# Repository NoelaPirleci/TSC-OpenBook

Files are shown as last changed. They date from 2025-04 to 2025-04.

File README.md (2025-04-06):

# TSC-OpenBook
# Descriere funcționalitate hardware

Proiectul se bazează pe microcontroller-ul **ESP32-C6**, care gestionează comunicarea cu toate componentele externe și senzorii conectați. Acest microcontroller oferă conectivitate **Wi-Fi** și **Bluetooth**, dar și suport pentru interfetele **SPI**, **I2C** și **UART**. Este conectat la 3V3 printr-un regulator de tensiune **LDO**, care primește energie de la o baterie **Li-Po** de 3.7V. 

Afisarea informațiilor se face utilizând un **display E-Paper** conectat prin **interfața SPI**, care are un consum redus de energie, fiind activ doar la actualizările ecranului. Informațiile afișate vor include data, ora, valorile senzorilor etc. 

Monitorizarea mediului se face cu ajutorul senzorului **BME688**, care măsoară temperatura, umiditatea și presiunea atmosferică, comunicând cu microcontroller-ul prin magistrala **I2C**. Modulul **RTC DS3231** este conectat și el la I2C și menține ora și data exactă, chiar și atunci când sistemul este oprit.

Prin **portul USB-C** se face alimentarea sistemului, care este conectat la circuitul de încărcare a bateriei utilizând **MCP73831**. Acesta controlează încărcarea bateriei Li-Po. Tensiunea va fi stabilită la **3.3V** pentru alimentarea senzorilor și a microcontroller-ului. Circuitul **MAX17048** este folosit pentru a monitoriza nivelul încărcării bateriei și furnizează informații despre tensiune și starea de încărcare prin I2C.

Consumul de energie este gestionat de ESP32-C6, care poate intra în **modul de consum redus**, permițând o durată lungă de viață a bateriei. Consumul în regim activ variază în funcție de sarcinile și componentele active în acel moment.

Pentru stocare, sistemul va folosi o **memorie externă NOR Flash**, conectată prin **SPI**, dar va exista și un slot pentru **card SD**, care va fi folosit pentru a loga local datele. Butoanele sunt conectate la **GPIO-uri** și vor fi folosite pentru resetare, bootare și alte acțiuni.

---

# Schema bloc

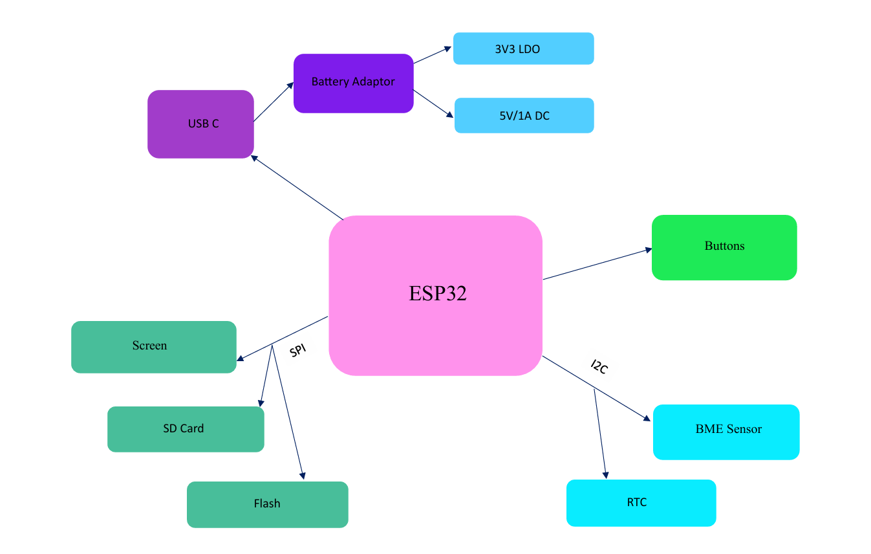
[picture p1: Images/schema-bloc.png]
scheme


# Descriere pini ESP32-C6

Pinii microcontroller-ului **ESP32-C6** sunt utilizați în cadrul a cinci categorii:

## 1. Interfața SPI
Este folosită pentru comunicarea componentelor care necesită viteze mari de transfer. Pinii utilizați sunt:
- **IO0**: linia **MOSI** unde microcontroller-ul va trimite date către perifericele SPI.
- **IO1**: linia **MISO** unde ESP32-C6 va primi date de la cardul SD.
- **IO2**: linia **SCK** care va genera semnalul de ceas pentru sincronizarea SPI.
- **IO3**: linia **CS** pentru memoria **Flash NOR**.
- **IO4**: linia **CS** pentru display-ul **E-paper**.
- **IO5**: linia **CS** pentru slotul de card **SD**.
- **IO6, IO7, IO8**: pentru semnalele de control ale **E-Paper**-ului: **reset**, **busy**, **data/command (DC)**. Acești pini sunt utilizați pentru a evita conflictele cu alte interfețe și permit o rutare eficientă a traseelor pe placă.

## 2. Interfața I2C
Este folosită pentru a conecta senzorii de mediu și circuitele de monitorizare a tensiunii sau a timpului. Această interfață va conecta componentele: **BME688**, **MAX17048**, **DS3231**. Pinii folosiți sunt:
- **IO15**: linia **SCL**, folosită pentru semnalul de ceas.
- **IO16**: linia **SDA**, care va transmite date bidirecțional între microcontroller și perifericele I2C. Acești pini sunt aleși pentru a nu se suprapune cu cei de la SPI sau UART și pentru a permite extinderea prin **Qwiic**.

## 3. Interfața UART
Este folosită pentru **debugging**, comunicare serială sau conectare la module externe. Pinii utilizați sunt:
- **IO17**: **TXD**, linia de ieșire a datelor de la ESP32 către PC sau consolă.
- **IO18**: **RXD**, linia de intrare a datelor către ESP32. Acești pini sunt utili în faza de dezvoltare pentru testare, dar pot fi folosiți și în aplicațiile finale, dacă UART nu este necesar.

## 4. Pini GPIO
Sunt folosiți pentru butoanele **boot**, **reset** sau **change**. Pinii utilizați sunt:
- **IO9**: este folosit pentru **BOOT** și permite intrarea în modul de programare.
- **EN**: este pinul hardware **RESET** al ESP32-C6.
- **IO10, IO11**: sunt utilizați pentru butoane suplimentare, care au diverse acțiuni în aplicație. Acești pini au fost aleși pentru că sunt disponibili în schema de referință ESP32-C6 și nu sunt partajați cu perifericele.

## 5. Alimentare
Pinii de alimentare sunt:
- **3V3**: este intrarea de alimentare stabilizată la 3.3V, provenind din regulatorul LDO alimentat de la bateria **Li-Po**.
- **GND**: conexiunea de masă.

# Bill of Materials

| CNT | VAL | Device | Package | Parts | PURCHASE | DATASHEET |
| --- | ----- | --- | --- | ----- | --- | --- |
| 1 |  | ADAFRUIT_LEDCHIP-LED0603 | 0603 | CHG_LED | https://www.digikey.com/en/products/detail/w%C3%BCrth-elektronik/150060RS75000/4489901 | https://www.we-online.com/components/products/datasheet/150060RS75000.pdf |
| 1 | 0.1uF/50V | ESP32_WROVER_EAGLE-LTSPICE_C0402 | 0402 | EPD_C3 | https://www.digikey.com/en/products/detail/samsung-electro-mechanics/CL05B104KB5NNNC/11696318 | https://weblib.samsungsem.com/mlcc/mlcc-ec-data-sheet.do?partNumber=CL05B104KB5NNN |
| 1 | 0.47 | ESP32_WROVER_EAGLE-LTSPICE_RR0402 | 0402 | R3 | https://www.digikey.com/en/products/detail/panasonic-electronic-components/ERJ-2BQJR47X/5647384 | https://industrial.panasonic.com/cdbs/www-data/pdf/RDN0000/AOA0000C313.pdf |
| 1 | 100K | ESP32_WROVER_EAGLE-LTSPICE_RR0402 | 0402 | R_PWRUSB | https://www.digikey.com/en/products/detail/panasonic-electronic-components/ERJ-2RKF1003X/192081 | https://industrial.panasonic.com/cdbs/www-data/pdf/RDA0000/AOA0000C304.pdf |
| 8 | 100nF | ESP32_WROVER_EAGLE-LTSPICE_C0402 | 0402 | C1, C2, C3_USB, C5, C7, C8, C9, C_DELAY | https://www.digikey.com/en/products/detail/samsung-electro-mechanics/CL05B104KP5NNNC/3886660 | https://mm.digikey.com/Volume0/opasdata/d220001/medias/docus/609/CL05B104KP5NNNC_Spec.pdf |
| 1 | 100uF | RCL_CPOL-EUCT3528 | 3528 | C_TANT | https://ro.mouser.com/ProductDetail/KEMET/T491B107M006AT?qs=U312oeP%2FpiHOgyk6KO2m0g%3D%3D | https://ro.mouser.com/datasheet/2/447/KEM_T2005_T491-3316937.pdf
| 16 | 10K | ESP32_WROVER_EAGLE-LTSPICE_RR0402 | 0402 | R1, R1_PINH1, R1_PINH2, R2-PINH1, R2_PINH2, R4, R5, R6, R7, R8, R9, R10, R_BOOT, R_CHANGE, R_CL1, R_RESET | https://www.digikey.com/en/products/detail/panasonic-electronic-components/ERJ-2RKF1002X/192073 | https://industrial.panasonic.com/cdbs/www-data/pdf/RDA0000/AOA0000C304.pdf |
| 1 | 10uF | ESP32_WROVER_EAGLE-LTSPICE_C0402 | 0402 | C6 | https://www.digikey.com/en/products/detail/samsung-electro-mechanics/CL05A106MP5NUNC/3887108 | https://mm.digikey.com/Volume0/opasdata/d220001/medias/docus/2614/CL05A106MP5NUNC_Spec.pdf |
| 1 | 112A-TAAR-R03_ATTEND | 112A-TAAR-R03_ATTEND |  | J4 | https://www.digikey.ro/en/products/detail/attend-technology/112A-TAAR-R03/17633923 | https://www.attend.com.tw/data/download/file/112A-TAAR-R03_Spec.pdf |
| 1 | 15 | ESP32_WROVER_EAGLE-LTSPICE_RR0402 | 0402 | R_CAPACITOR | https://www.digikey.com/en/products/detail/panasonic-electronic-components/ERJ-2RKF15R0X/192142 | https://industrial.panasonic.com/cdbs/www-data/pdf/RDA0000/AOA0000C304.pdf |
| 1 | 1uF | ESP32_WROVER_EAGLE-LTSPICE_C0402 | 0402 | C4 | https://www.digikey.com/en/products/detail/samsung-electro-mechanics/CL05A105KO5NNNC/3886725 | https://mm.digikey.com/Volume0/opasdata/d220001/medias/docus/609/CL05A105KO5NNNC_Spec_5-2-19.pdf |
| 9 | 1uF/50V | ESP32_WROVER_EAGLE-LTSPICE_C0402 | 0402 | EPD_C1, EPD_C2, EPD_C4, EPD_C5, EPD_C6, EPD_C7, EPD_C8, EPD_C9, EPD_C10 | https://www.digikey.com/en/products/detail/murata-electronics/GRM155R61H105KE05D/13531808 | https://search.murata.co.jp/Ceramy/image/img/A01X/G101/ENG/GRM155R61H105KE05-01A.pdf |
| 1 | 2.2 | ESP32_WROVER_EAGLE-LTSPICE_RR0402 | 0402 | R2 | https://www.digikey.com/en/products/detail/panasonic-electronic-components/ERJ-2GEJ2R2X/282078 | https://api.pim.na.industrial.panasonic.com/file_stream/main/fileversion/1242 |
| 1 | 200 | ESP32_WROVER_EAGLE-LTSPICE_RR0402 | 0402 | R1_BAT | https://www.digikey.com/en/products/detail/panasonic-electronic-components/ERJ-2RKF2000X/192215 | https://industrial.panasonic.com/cdbs/www-data/pdf/RDA0000/AOA0000C304.pdf |
| 2 | 20V/4.2A/52mO/1.4W | ESP32_WROVER_SPARKFUN-DISCRETESEMI_MOSFET_PCH-DMG2305UX-7 |  | Q1, Q2 | https://www.digikey.ro/en/products/detail/diodes-incorporated/DMG2305UX-7/4340667 | https://www.diodes.com/assets/Datasheets/DMG2305UX.pdf |
| 1 | 2K | ESP32_WROVER_EAGLE-LTSPICE_RR0402 | 0402 | R2_BAT | https://www.digikey.com/en/products/detail/panasonic-electronic-components/ERJ-2RKF2001X/192194 | https://industrial.panasonic.com/cdbs/www-data/pdf/RDA0000/AOA0000C304.pdf |
| 5 | 4.7uF | ESP32_WROVER_EAGLE-LTSPICE_C0402 | 0402 | C1_BAT, C1_BAT1, C2_BAT, C2_BAT1, C4_USB | https://www.digikey.com/en/products/detail/samsung-electro-mechanics/CL05A475KQ5NRNC/3887139 | https://mm.digikey.com/Volume0/opasdata/d220001/medias/docus/41/CL05A475KQ5NRNC_Spec.pdf |
| 1 | 4.7uF/25V | ESP32_WROVER_EAGLE-LTSPICE_C0402 | 0402 | C3 | https://www.digikey.com/en/products/detail/murata-electronics/GRM155C61E475ME15D/16821133 | https://search.murata.co.jp/Ceramy/image/img/A01X/G101/ENG/GRM155C61E475ME15-01A.pdf |
| 2 | 5k1 | ESP32_WROVER_EAGLE-LTSPICE_RR0402 | 0402 | R1_USB, R2_USB | https://www.digikey.com/en/products/detail/panasonic-electronic-components/ERJ-2GEJ512X/147044 | https://api.pim.na.industrial.panasonic.com/file_stream/main/fileversion/1242 |
| 1 | 68uH | 744043680IND_4828-WE-TPC_WRE |  | L1 | https://www.digikey.de/en/products/detail/w%C3%BCrth-elektronik/744043680/1638515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 | https://www.we-online.com/components/products/datasheet/744043680.pdf |
| 1 | BD5229G-TR | BD5229G-TR |  | U6 | https://www.digikey.com/en/products/detail/rohm-semiconductor/BD5229G-TR/658502 | https://www.rohm.com/datasheet?p=BD5229G&dist=Digi-key&media=referral&source=digi-key.com&campaign=Digi-key |
| 1 | BME688 | ESP32_WROVER_BME680_BME680 |  | U8 | https://www.digikey.ro/en/products/detail/bosch-sensortec/BME688/13681261 | https://www.bosch-sensortec.com/media/boschsensortec/downloads/datasheets/bst-bme688-ds000.pdf |
| 3 | BUTTON_CUSYOMV1 | BUTTON_CUSYOMV1 |  | BOOT_BUTTON, CHANGE_BUTTON, RESET_BUTTON |  |  |
| 1 | CPH3225A | CPH3225A |  | C_SUPERCAP | https://www.digikey.com/en/products/detail/seiko-instruments/CPH3225A/8692444 | https://mm.digikey.com/Volume0/opasdata/d220001/medias/docus/6537/rev05-CPHCPM.pdf |
| 1 | DS3231SN# | DS3231SN# |  | U3 | https://www.digikey.com/en/products/detail/analog-devices-inc-maxim-integrated/DS3231SN/1197576 | https://www.analog.com/media/en/technical-documentation/data-sheets/DS3231.pdf |
| 1 | ESP32-C6-WROOM-1-N8 | ESP32-C6-WROOM-1-N8 |  | U1 | https://www.digikey.com/en/products/detail/espressif-systems/ESP32-C6-WROOM-1-N8/17728866 | https://www.espressif.com/sites/default/files/documentation/esp32-c6-wroom-1_wroom-1u_datasheet_en.pdf |
| 1 | ESP32C6_VARISTORCN1812 | ESP32C6_VARISTORCN1812 |  | PFMF.050.1 | https://www.digikey.com/en/products/detail/schurter-inc/PFMF-050-2/1731348 | https://us.schurter.com/en/datasheet/typ_PFMF.pdf |
| 2 | ESP32_WROVER_AVX---SD0805S020S1R0 | ESP32_WROVER_AVX---SD0805S020S1R0 |  | D2, D7 | https://www.digikey.gr/en/products/detail/kyocera-avx/SD0805S020S1R0/3749517 | https://datasheets.kyocera-avx.com/schottky.pdf |
| 1 | FH34SRJ-24S-0.5SH_99_ | FH34SRJ-24S-0.5SH_99_ |  | J1 | https://www.digikey.com/en/products/detail/hirose-electric-co-ltd/FH34SRJ-24S-0-5SH-99/5132529 | https://www.hirose.com/en/product/document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 |
| 1 | MAX17048G+T10 | MAX17048G+T10 |  | U2 | https://www.digikey.com/en/products/detail/analog-devices-inc-maxim-integrated/MAX17048G-T10/3758921 | https://datasheets.maximintegrated.com/en/ds/MAX17048-MAX17049.pdf |
| 3 | MBR0530 | MBR0530 |  | D3, D4, D5 | https://eu.mouser.com/ProductDetail/Micro-Commercial-Components-MCC/MBR0530-TP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 | https://eu.mouser.com/datasheet/2/258/MBR0520_MBR0580_SOD123_-2492194.pdf |
| 1 | MCP73831 | ESP32_WROVER_SPARKFUN-IC-POWER_MCP73831 |  | U7 | https://www.digikey.com/en/products/detail/microchip-technology/MCP73831T-2ACI-OT/964301 | https://ww1.microchip.com/downloads/en/DeviceDoc/MCP73831-Family-Data-Sheet-DS20001984H.pdf |
| 6 | PGB1010603MR | PGB1010603MR |  | D6, D8, D9, D10, D11, D12 | https://www.digikey.com/en/products/detail/littelfuse-inc/PGB1010603MR/715755 | https://www.littelfuse.com/assetdocs/pulseguard-esd-suppressors-pgb1-datasheet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 |
| 1 | QWIIC_RIGHT_ANGLE | QWIIC_CONNECTORJS-1MM |  | J3 | https://www.sparkfun.com/qwiic-jst-connector-smd-4-pin-horizontal.html | https://cdn.sparkfun.com/assets/parts/1/2/2/8/9/Qwiic_Connector_Datasheet.pdf |
| 1 | SAMACSYS_PARTS_USB4110-GF-A | SAMACSYS_PARTS_USB4110-GF-A |  | J2 | https://www.digikey.ro/en/products/detail/gct/USB4110-GF-A/10384547 | https://gct.co/files/specs/usb4110-spec.pdf?v=6b2a6292-70a5-4bd5-a7e5-0f3fe03e015f |
| 1 | SI1308EDL-T1-GE3 | SI1308EDL-T1-GE3 |  | Q3 | https://www.digikey.com/en/products/detail/vishay-siliconix/SI1308EDL-T1-GE3/4876435 | https://www.vishay.com/docs/63399/si1308edl.pdf |
| 1 | USBLC6-2SC6Y | USBLC6-2SC6Y |  | D1 | https://www.digikey.com/en/products/detail/stmicroelectronics/USBLC6-2SC6Y/2819177 | https://www.st.com/content/ccc/resource/technical/document/datasheet/group0/94/15/6c/58/ba/91/46/42/DM00055262/files/DM00055262.pdf/jcr:content/translations/en.DM000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 |
| 1 | W25Q512JVEIQ | W25Q512JVEIQ |  | U4 | https://www.digikey.com/en/products/detail/winbond-electronics/W25Q512JVEIQ/10244706 | https://www.winbond.com/resource-files/W25Q512JV%20SPI%20RevB%2006252019%20KMS.pdf |
| 1 | XC6220A331MR-G | XC6220A331MR-G |  | U5 | https://www.digikey.in/en/products/detail/torex-semiconductor-ltd/XC6220A331MR-G/10165775 | https://product.torexsemi.com/system/files/series/xc6220.pdf |

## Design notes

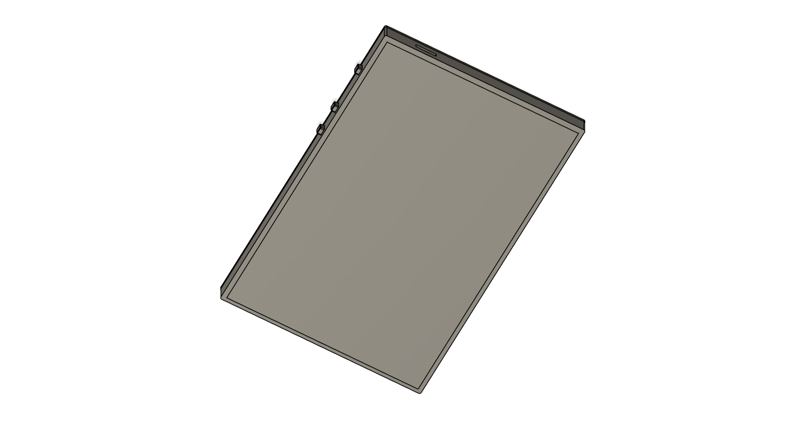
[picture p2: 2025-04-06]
Images/front_image.png

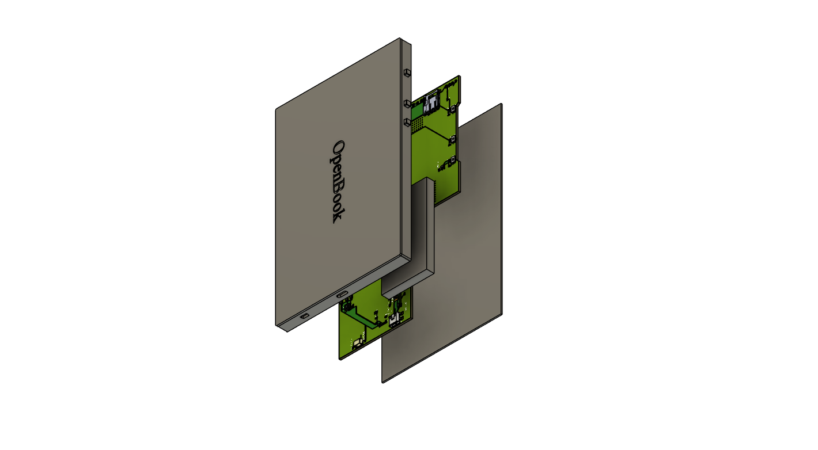
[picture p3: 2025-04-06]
Images/exploded_view.png

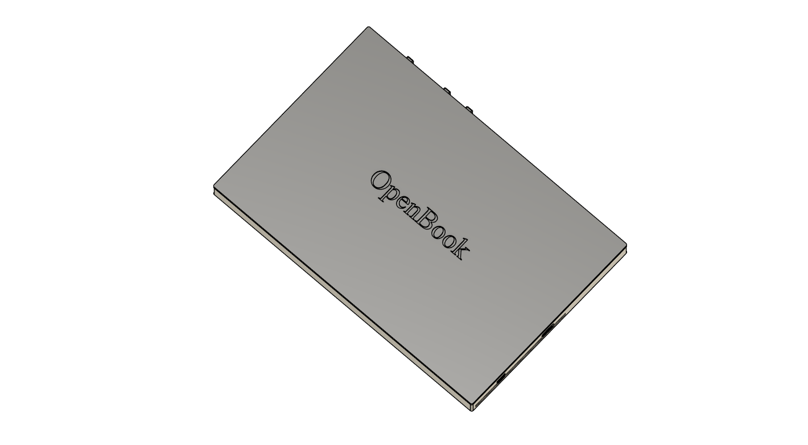
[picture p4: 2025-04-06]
Images/back_image.png

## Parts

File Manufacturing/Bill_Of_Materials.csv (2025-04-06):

Qty | Value | Device | Package | Parts | Description | ARROW_PART_NUMBER | ARROW_PRICE-STOCK | DESCRIPTION | HEIGHT | MANUFACTURER_NAME | MANUFACTURER_PART_NUMBER | MOUSER_PART_NUMBER | MOUSER_PRICE-STOCK | POPULARITY
1 |  | ADAFRUIT_LED | ADAFRUIT_CHIP-LED0603 | CHG_LED | LED
1 |  | SJ | SJ | SJ1 | SMD solder JUMPER |  |  |  |  |  |  |  |  | 3
1 | 0.47 | ESP32_WROVER_EAGLE-LTSPICE_R | ESP32_WROVER_EAGLE-LTSPICE_R0402 | R3 | RESISTOR, European symbol
1 | 100K | ESP32_WROVER_EAGLE-LTSPICE_R | ESP32_WROVER_EAGLE-LTSPICE_R0402 | R1_PWRUSB | RESISTOR, European symbol
4 | 100nF | EAGLE-LTSPICE_C | ESP32_WROVER_EAGLE-LTSPICE_C0402 | C1, C4_USB, C9, C_DELAY | CAPACITOR, European symbol
4 | 100nF | ESP32_WROVER_EAGLE-LTSPICE_C | ESP32_WROVER_EAGLE-LTSPICE_C0402 | C2, C6, C8, C10 | CAPACITOR, European symbol
1 | 100uF TANT | RCL_CPOL-EU | RCL_CT3528 | C3 | POLARIZED CAPACITOR, European symbol
16 | 10K | ESP32_WROVER_EAGLE-LTSPICE_R | ESP32_WROVER_EAGLE-LTSPICE_R0402 | R1, R1-PINH, R1_PINH1, R2-PINH, R2_PINH1, R4, R5, R6, R7, R8, R9, R10, R_BOOT, R_CHANGE, R_CL1, R_RESET | RESISTOR, European symbol
1 | 10uF | ESP32_WROVER_EAGLE-LTSPICE_C | ESP32_WROVER_EAGLE-LTSPICE_C0402 | C7 | CAPACITOR, European symbol
1 | 112A-TAAR-R03_ATTENDSDCARD | 112A-TAAR-R03_ATTENDSDCARD | 112ATAARR03ATTEND | J4 | Micro SD Card Socket, Push-Push Type, Top Mount, SMT, H=1.83mm, 10u
1 | 15 | ESP32_WROVER_EAGLE-LTSPICE_R | ESP32_WROVER_EAGLE-LTSPICE_R0402 | R_CAPACITOR | RESISTOR, European symbol
1 | 1uF | ESP32_WROVER_EAGLE-LTSPICE_C | ESP32_WROVER_EAGLE-LTSPICE_C0402 | C5 | CAPACITOR, European symbol
10 | 1uF/50V | ESP32_WROVER_EAGLE-LTSPICE_C | ESP32_WROVER_EAGLE-LTSPICE_C0402 | EPD_C1, EPD_C2, EPD_C5, EPD_C6, EPD_C7, EPD_C8, EPD_C9, EPD_C10, EPD_C11, EPD_C12 | CAPACITOR, European symbol
1 | 2.2 | ESP32_WROVER_EAGLE-LTSPICE_R | ESP32_WROVER_EAGLE-LTSPICE_R0402 | R2 | RESISTOR, European symbol
1 | 200 | ESP32_WROVER_EAGLE-LTSPICE_R | ESP32_WROVER_EAGLE-LTSPICE_R0402 | R1_BAT | RESISTOR, European symbol
2 | 20V/4.2A/52m?/1.4W | ESP32_WROVER_SPARKFUN-DISCRETESEMI_MOSFET_PCH | ESP32_WROVER_SPARKFUN-DISCRETESEMI_SOT23-3 | Q1, Q2 | P-channel MOSFETs
1 | 2K | ESP32_WROVER_EAGLE-LTSPICE_R | ESP32_WROVER_EAGLE-LTSPICE_R0402 | R2_BAT | RESISTOR, European symbol
1 | 4.7uF | EAGLE-LTSPICE_C | ESP32_WROVER_EAGLE-LTSPICE_C0402 | C5_USB | CAPACITOR, European symbol
4 | 4.7uF | ESP32_WROVER_EAGLE-LTSPICE_C | ESP32_WROVER_EAGLE-LTSPICE_C0402 | C1_BAT, C1_BAT1, C1_BAT2, C2_BAT | CAPACITOR, European symbol
1 | 4.7uF/25V | EAGLE-LTSPICE_C | ESP32_WROVER_EAGLE-LTSPICE_C0402 | C4 | CAPACITOR, European symbol
2 | 5k1 | ESP32_WROVER_EAGLE-LTSPICE_R | ESP32_WROVER_EAGLE-LTSPICE_R0402 | R2-USB, R2-USB1 | RESISTOR, European symbol
1 | 68uH | 744043680 | IND_4828-WE-TPC_WRE | L1
1 | BD5229G-TRBD5229 | BD5229G-TRBD5229 | SOT95P280X125-5N | IC1 | Voltage Detector with Adjustable Delay Time: CMOS processes are utilized to develop high precision, low current consumption CMOS reset ICs that allow arbitrary setting of the delay time. The extensive lineup includes both Nch Open Drain and CMOS output types in a wide range of detection voltages (from 2.3V to 6.0V, in 0.1V steps), enabling selection of the ideal solution based on customer requirements. In addition, the entire series is of course both lead-free and RoHS-compliant.
3 | BUTTON_CUSYOMV1BUTON | BUTTON_CUSYOMV1BUTON | MYBUTTON | BOOT_BUTTON, CHANGE_BUTTON, RESET_BUTTON
1 | CPH3225ASUPERCAP | CPH3225ASUPERCAP | CAPCP3225X100N | C10_SUPERCAP | Cap 0.011F 3.3V 1210 Flat Check availability
1 | DS3231SN#DS3231 | DS3231SN#DS3231 | SOIC127P1032X265-16N | U3 | Real Time Clock Serial 16-Pin SOIC W T/R Check availability
1 | ESP32-C6-WROOM-1-N8 | ESP32-C6-WROOM-1-N8ESP32 | XCVR_ESP32-C6-WROOM-1-N8 | U2 | Check availability
1 | ESP32C6_VARISTOR | ESP32C6_VARISTOR | ESP32C6_VARISTOR_CT/CN1812 | PFMF.050.1 | VARISTOR
2 | ESP32_WROVER_AVX---SD0805S020S1R0_AVX_SD0805S020S1R0_0_0 | ESP32_WROVER_AVX---SD0805S020S1R0_AVX_SD0805S020S1R0_0_0 | ESP32_WROVER_AVX---SD0805S020S1R0_AVX_SD0805S020S1R0_0 | D2, D7 | Schottky Barrier Rectifier Diode
1 | ESP32_WROVER_BME680_BME680BME | ESP32_WROVER_BME680_BME680BME | ESP32_WROVER_BME680_PSON80P300X300X100-8N | SENSOR2 | Integrated Environmental Unit
1 | ESP32_WROVER_SPARKFUN-IC-POWER_MCP73831ICPOWER | ESP32_WROVER_SPARKFUN-IC-POWER_MCP73831ICPOWER | ESP32_WROVER_SPARKFUN-IC-POWER_SOT23-5 | MCP73831 | MCP73831T Li-Ion, Li-Pol Controller
1 | FH34SRJ-24S-0.5SH_99_FH34 | FH34SRJ-24S-0.5SH_99_FH34 | FH34SRJ24S05SH99 | J1 | (0.50mm) Surface Mount, Right Angle
1 | MAX17048G+T10MAX170 | MAX17048G+T10MAX170 | SON50P200X200X80-9N | U4 | Check availability
3 | MBR0530MBR | MBR0530MBR | SOD3716X135N | D3, D4, D5 | ON SEMICONDUCTOR - MBR0530 - DIODE, SCHOTTKY, 0.5A, 30V, SOD-123
6 | PGB1010603MRDIOC | PGB1010603MRDIOC | DIOC1608X36N | D6, D8, D9, D10, D11, D12 | Check availability
1 | QWIIC_RIGHT_ANGLE | QWIIC_CONNECTOR | JST04_1MM_RA | J3 | SparkFun I2C Standard Qwiic Connector
1 | SAMACSYS_PARTS_USB4110-GF-AUSB | SAMACSYS_PARTS_USB4110-GF-AUSB | SAMACSYS_PARTS_USB4110GFA | J2 | CONN USB 2.0 TYPE-C R/A SMT
1 | SI1308EDL-T1-GE3SI13 | SI1308EDL-T1-GE3SI13 | SOT65P210X110-3N | Q3 | MOSFET N-Ch 30V 1.5A TrenchFET SC70 Vishay Si1308EDL-T1-GE3 N-channel MOSFET Transistor, 1.5 A, 30 V, 3-Pin SC-70
12 | TPMODEL | TPMODEL | TP20R | TP1, TP2, TP3, TP7, TP8, TP9, TP10, TP12, TP13, TP15, TP16, TP17 | Test pad
5 | TPTP20R | TPMODEL | TP20R | TP4, TP5, TP6, TP11, TP14 | Test pad
1 | USBLC6-2SC6YUSBL | USBLC6-2SC6YUSBL | SOT95P280X145-6N | D1 | Low Cap. ESD Protection Auto SOT-23-6 STMicroelectronics USBLC6-2SC6Y, Dual Uni-Directional TVS Diode Array, 6-Pin SOT-23
1 |  |  | SON127P600X800X80-9N | U1 | Check availability
1 | XC6220A331MR-G | XC6220A331MR-G | SOT95P280X120-5N | IC4 | LDO Voltage Regulators |  |  | LDO Voltage Regulators | 1.2mm | Torex | XC6220A331MR-G | 865-XC6220A331MR-G | https://www.mouser.co.uk/ProductDetail/Torex-Semiconductor/XC6220A331MR-G?qs=AsjdqWjXhJ8ZSWznL1J0gg%3D%3D

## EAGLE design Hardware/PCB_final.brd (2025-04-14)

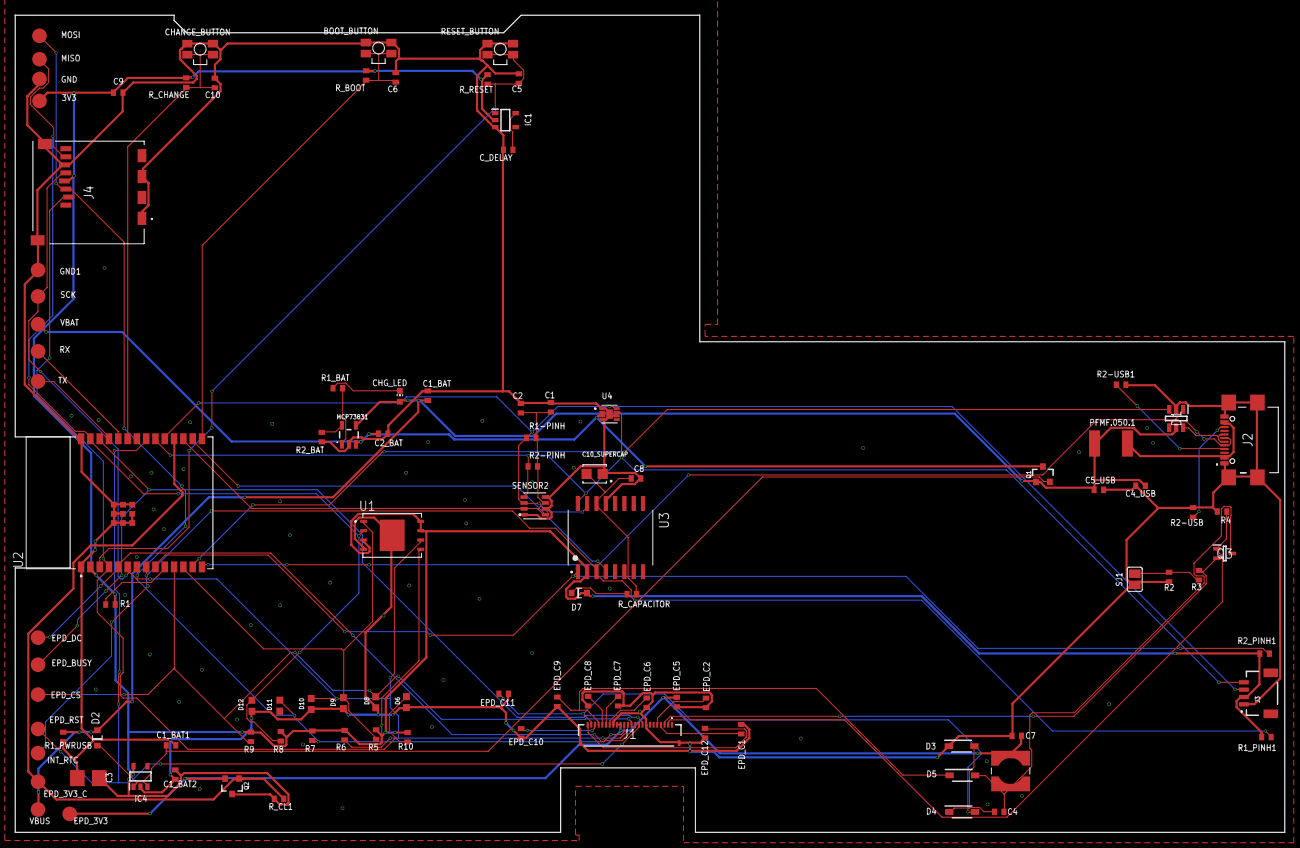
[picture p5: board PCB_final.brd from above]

Board: 2 copper layers, 173.4 x 111.6 mm, 103 parts (0 on the bottom side), 55 nets.

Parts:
3V3: TPMODEL; TP20R
BOOT_BUTTON: BUTTON_CUSYOMV1BUTON; MYBUTTON
C1, C2, C4_USB, C6, C8, C9, C10: 100nF; ESP32_WROVER_EAGLE-LTSPICE_C0402
C1_BAT, C1_BAT1, C1_BAT2, C2_BAT, C5_USB: 4.7uF; ESP32_WROVER_EAGLE-LTSPICE_C0402
C3: 100uF TANT; RCL_CT3528
C4: 4.7uF/25V; ESP32_WROVER_EAGLE-LTSPICE_C0402
C5: 1uF; ESP32_WROVER_EAGLE-LTSPICE_C0402
C7: 10uF; ESP32_WROVER_EAGLE-LTSPICE_C0402
C10_SUPERCAP: CPH3225ASUPERCAP; CAPCP3225X100N
CHANGE_BUTTON: BUTTON_CUSYOMV1BUTON; MYBUTTON
CHG_LED: ADAFRUIT_CHIP-LED0603
C_DELAY: 100nF; ESP32_WROVER_EAGLE-LTSPICE_C0402
D1: USBLC6-2SC6YUSBL; SOT95P280X145-6N
D2, D7: ESP32_WROVER_AVX---SD0805S020S1R0_AVX_SD0805S020S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; ESP32_WROVER_AVX---SD0805S020S1R0_AVX_SD0805S020S1R0_0
D3, D4, D5: MBR0530MBR; SOD3716X135N
D6, D8, D9, D10, D11, D12: PGB1010603MRDIOC; DIOC1608X36N
EPD_3V3, EPD_3V3_C: TPMODEL; TP20R
EPD_BUSY: TPMODEL; TP20R
EPD_C1, EPD_C2, EPD_C5, EPD_C6, EPD_C7, EPD_C8, EPD_C9, EPD_C10, EPD_C11, EPD_C12: 1uF/50V; ESP32_WROVER_EAGLE-LTSPICE_C0402
EPD_CS: TPMODEL; TP20R
EPD_DC: TPTP20R; TP20R
EPD_RST: TPMODEL; TP20R
GND, GND1: TPTP20R; TP20R
IC1: BD5229G-TRBD5229; SOT95P280X125-5N
IC4: XC6220A331MR-G; SOT95P280X120-5N
INT_RTC: TPMODEL; TP20R
J1: FH34SRJ-24S-0.5SH_99_FH34; FH34SRJ24S05SH99
J2: SAMACSYS_PARTS_USB4110-GF-AUSB; SAMACSYS_PARTS_USB4110GFA
J3: QWIIC_RIGHT_ANGLE; JST04_1MM_RA
J4: 112A-TAAR-R03_ATTENDSDCARD; 112ATAARR03ATTEND
L1: 68uH; IND_4828-WE-TPC_WRE
MCP73831: ESP32_WROVER_SPARKFUN-IC-POWER_MCP73831ICPOWER; ESP32_WROVER_SPARKFUN-IC-POWER_SOT23-5
MISO: TPTP20R; TP20R
MOSI: TPMODEL; TP20R
PFMF.050.1: ESP32C6_VARISTOR; ESP32C6_VARISTOR_CT/CN1812
Q1, Q2: 20V/4.2A/52mΩ/1.4W; ESP32_WROVER_SPARKFUN-DISCRETESEMI_SOT23-3
Q3: SI1308EDL-T1-GE3SI13; SOT65P210X110-3N
R1, R1-PINH, R1_PINH1, R2-PINH, R2_PINH1, R4, R5, R6, R7, R8, R9, R10: 10K; ESP32_WROVER_EAGLE-LTSPICE_R0402
R1_BAT: 200; ESP32_WROVER_EAGLE-LTSPICE_R0402
R1_PWRUSB: 100K; ESP32_WROVER_EAGLE-LTSPICE_R0402
R2: 2.2; ESP32_WROVER_EAGLE-LTSPICE_R0402
R2-USB, R2-USB1: 5k1; ESP32_WROVER_EAGLE-LTSPICE_R0402
R2_BAT: 2K; ESP32_WROVER_EAGLE-LTSPICE_R0402
R3: 0.47; ESP32_WROVER_EAGLE-LTSPICE_R0402
RESET_BUTTON: BUTTON_CUSYOMV1BUTON; MYBUTTON
RX: TPMODEL; TP20R
R_BOOT: 10K; ESP32_WROVER_EAGLE-LTSPICE_R0402
R_CAPACITOR: 15; ESP32_WROVER_EAGLE-LTSPICE_R0402
R_CHANGE: 10K; ESP32_WROVER_EAGLE-LTSPICE_R0402
R_CL1: 10K; ESP32_WROVER_EAGLE-LTSPICE_R0402
R_RESET: 10K; ESP32_WROVER_EAGLE-LTSPICE_R0402
SCK: TPMODEL; TP20R
SENSOR2: ESP32_WROVER_BME680_BME680BME; ESP32_WROVER_BME680_PSON80P300X300X100-8N
SJ1: SJ
TX: TPMODEL; TP20R
U1: W25Q512JVEIQ"; SON127P600X800X80-9N
U2: ESP32-C6-WROOM-1-N8; XCVR_ESP32-C6-WROOM-1-N8
U3: DS3231SN#DS3231; SOIC127P1032X265-16N
U4: MAX17048G+T10MAX170; SON50P200X200X80-9N
VBAT: TPMODEL; TP20R
VBUS: TPTP20R; TP20R

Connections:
3V3: 3V3.TP, C1_BAT2.1, C3.+, C9.1, D7.2, IC1.2, IC4.5, J3.2, J4.P4, Q2.3, R1.2, R1_PINH1.2, R2_PINH1.2, R5.2, R6.2, R7.2, R8.2, R9.2, R10.2, R_BOOT.2, R_CHANGE.2, R_CL1.2, R_RESET.2, U1.3, U1.7, U1.8, U2.2, U3.2
32KHZ: R2_PINH1.1, U2.9, U3.1
DN: D1.4, J2.A7, J2.B7
DP: D1.6, J2.A6, J2.B6
EPD_3V3: C7.1, EPD_3V3.TP, EPD_C5.2, J1.15, J1.16, L1.2, Q2.2
EPD_3V3_C: EPD_3V3_C.TP, Q2.1, R_CL1.1, U2.18
EPD_BUSY: EPD_BUSY.TP, J1.9, U2.26
EPD_CS: D8.2, EPD_CS.TP, J1.12, R9.1, U2.11
EPD_DC: EPD_DC.TP, J1.11, U2.5
EPD_RST: EPD_RST.TP, J1.10, U2.21
FLASH_CS: D9.2, R5.1, U1.1, U2.12
GDR: J1.2, Q3.1, R4.2
GND: BOOT_BUTTON.1, BOOT_BUTTON.2, C1.2, C1_BAT.2, C1_BAT1.2, C1_BAT2.2, C2.2, C2_BAT.2, C3.-, C4_USB.2, C5.2, C5_USB.2, C6.2, C7.2, C8.2, C9.2, C10.2, C10_SUPERCAP.1, CHANGE_BUTTON.1, CHANGE_BUTTON.2, C_DELAY.2, D1.2, D3.1, D6.1, D8.1, D9.1, D10.1, D12.1, EPD_C1.1, EPD_C2.1, EPD_C5.1, EPD_C6.1, EPD_C7.1, EPD_C8.1, EPD_C9.1, EPD_C10.1, EPD_C11.1, EPD_C12.1, GND.TP, GND1.TP, IC1.3, IC4.2, J1.8, J1.17, J1.MP1, J1.MP2, J2.A1, J2.A12, J2.B1, J2.B12, J2.MP1, J2.MP2, J2.MP3, J2.MP4, J3.1, J4.G1, J4.G2, J4.G3, J4.G4, J4.P6, MCP73831.2, R1_PWRUSB.1, R2.1, R2-USB.2, R2-USB1.1, R2_BAT.1, R4.1, RESET_BUTTON.1, RESET_BUTTON.2, SENSOR2.1, SENSOR2.5, SENSOR2.7, SJ1.1, U1.4, U1.9, U2.1, U2.28, U2.29_1, U2.29_2, U2.29_3, U2.29_4, U2.29_5, U2.29_6, U2.29_7, U2.29_8, U2.29_9, U3.13, U4.1, U4.4, U4.6, U4.9
GPIO8: R1.1, U2.10
I2C_PW: C1.1, C2.1, R1-PINH.2, R2-PINH.2, SENSOR2.2, SENSOR2.6, SENSOR2.8, U2.17
INT_RTC: INT_RTC.TP, R1_PINH1.1, U2.8, U3.3
IO/BOOT: BOOT_BUTTON.3, BOOT_BUTTON.4, C6.1, R_BOOT.1, U2.15
IO/CHANGE: C10.1, CHANGE_BUTTON.3, CHANGE_BUTTON.4, R_CHANGE.1, U2.23
MISO: D12.2, J4.P7, MISO.TP, R8.1, U1.2, U2.27
MOSI: D11.2, J1.14, J4.P3, MOSI.TP, R7.1, U1.5, U2.7
unnamed: J2.B5, R2-USB.1
unnamed: J2.A5, R2-USB1.2
unnamed: C1_BAT1.1, D2.1, IC4.1, IC4.3, Q1.2
unnamed: C4.1, D3.2, D4.1
unnamed: CHG_LED.C, R1_BAT.1
unnamed: MCP73831.1, R1_BAT.2
unnamed: MCP73831.5, R2_BAT.2
unnamed: EPD_C12.2, J1.24
unnamed: EPD_C8.2, J1.20
unnamed: EPD_C10.2, J1.22
unnamed: EPD_C7.2, J1.19
unnamed: EPD_C6.2, J1.18
unnamed: EPD_C2.2, J1.5
unnamed: EPD_C1.2, J1.4
unnamed: C_DELAY.1, IC1.5
unnamed: D7.1, R_CAPACITOR.1
PREVGH: D5.1, EPD_C9.2, J1.21
PREVGL: D4.2, EPD_C11.2, J1.23
RESE: J1.3, Q3.2, R3.2
RESE': R2.2, R3.1, SJ1.2
RESET: C5.1, IC1.1, RESET_BUTTON.3, RESET_BUTTON.4, R_RESET.1, U2.3
RTC_RST: U2.16, U3.4
RX: RX.TP, U2.24
SCK: D10.2, J1.13, J4.P5, R6.1, SCK.TP, U1.6, U2.6
SCL: J3.4, R2-PINH.1, SENSOR2.4, U2.20, U3.16, U4.7
SDA: J3.3, R1-PINH.1, SENSOR2.3, U2.19, U3.15, U4.8
SRC: C4.2, D5.2, L1.1, Q3.3
SS_SD: D6.2, J4.P2, R10.1, U2.4
TX: TX.TP, U2.25
USB_D+: D1.1, U2.14
USB_D-: D1.3, U2.13
VBAT: C2_BAT.1, MCP73831.3, Q1.3, U4.2, U4.3, VBAT.TP
VBUS: C1_BAT.1, C4_USB.1, C5_USB.1, CHG_LED.A, D1.5, D2.2, MCP73831.4, PFMF.050.1.2, Q1.1, R1_PWRUSB.2, VBUS.TP
VRTC: C8.1, C10_SUPERCAP.2, R_CAPACITOR.2, U3.14
VUSB: J2.A4, J2.A9, J2.B4, J2.B9, PFMF.050.1.1

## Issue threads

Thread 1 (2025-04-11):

PCB measurements placed on incorrect layer

iarinapopa13, 2025-04-11:
When inspected the PCB, I've noticed that the dimension measurements are placed on the top layer instead of the dedicated measurements layer. These need to be moved to the proper measurements layer for correct design organization.

Closed 2025-04-14.

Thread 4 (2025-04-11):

Improper GND pour implementation causing visual artifacts

iarinapopa13, 2025-04-11:
The ground plane implementation shows irregular coverage with large red and blue areas that don't appear to be properly connected to the GND network. The pour needs to be reconfigured to ensure proper ground connectivity throughout the PCB without the visual artifacts shown in the screenshot.

Closed 2025-04-14.

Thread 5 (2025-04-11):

Connectors misaligned with enclosure openings in 3D model

iarinapopa13, 2025-04-11:
In the 3D model, I have seen when moving the object that the connectors are not properly aligned with the corresponding holes in the enclosure. Position adjustment of the connectors is needed to ensure proper fit with the enclosure openings.

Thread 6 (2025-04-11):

PCB Test Pad labels do not match associated signals

iarinapopa13, 2025-04-11:
The Test Pads on the PCB don't have the correct names according to their associated labels. The TP designations need to be renamed to properly reflect the signals they are measuring.

Closed 2025-04-14.

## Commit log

2025-04-06 Added PCB.
    [PCB.brd]
2025-04-06 Added Gerber Files.
2025-04-06 Added Bill of Materials.
    [Bill_Of_Materials.csv]
2025-04-06 Added Pick and Place file.
    [Pick_and_Place.csv]
2025-04-14 Add final electric schematic.
    [final_electric_schematic.sch]
2025-04-14 Add final PCB board design.
    [PCB_final.brd]
2025-04-14 Remove old PCB.
    [PCB.brd]
